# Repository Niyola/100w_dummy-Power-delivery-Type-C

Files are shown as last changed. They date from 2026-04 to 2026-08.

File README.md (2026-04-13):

USB Type-C Power Delivery Tester

A USB-C Power Delivery tester and 100W dummy load, built as part of my Master's thesis at Brno University of Technology.

The board negotiates a USB-PD contract with any USB-C charger, power bank, or laptop, requests different voltages (5V, 9V, 12V, 15V, 20V), and measures what is actually being delivered in real time. It handles up to 100W.

What's inside

The STM32F072CB runs the USB-PD protocol stack. The FUSB302B from onsemi handles the CC line communication. The INA237 from Texas Instruments measures voltage and current on VBUS bidirectionally. It is a 4-layer board, roughly 100mm by 60mm, with dedicated inner planes for ground and 3.3V.

References I used

Twonkie v2.0 by dojoe — https://github.com/dojoe/Twonkie/tree/master
An open source USB-PD sniffer. I followed its approach for the FUSB302B wiring and the CC line level shifting.

TI TPS25751EVM — https://www.ti.com/tool/TPS25751EVM
Texas Instruments' official USB-PD evaluation board. I used it as a reference for the high-current VBUS layout and current sensing.

What I changed

I use a single INA237 for bidirectional current sensing instead of two separate chips. I added a screw terminal output so the board works as a dummy load tester, not just a sniffer. I redesigned the stackup as 4 layers with full ground and 3.3V planes for better power integrity at 100W. I also added test points for bring-up.

About me

Eniola Adesuyi, M.Sc. Communications and Networking, Brno University of Technology. Supervised by Ing. Ondřej Krajsa, Ph.D.

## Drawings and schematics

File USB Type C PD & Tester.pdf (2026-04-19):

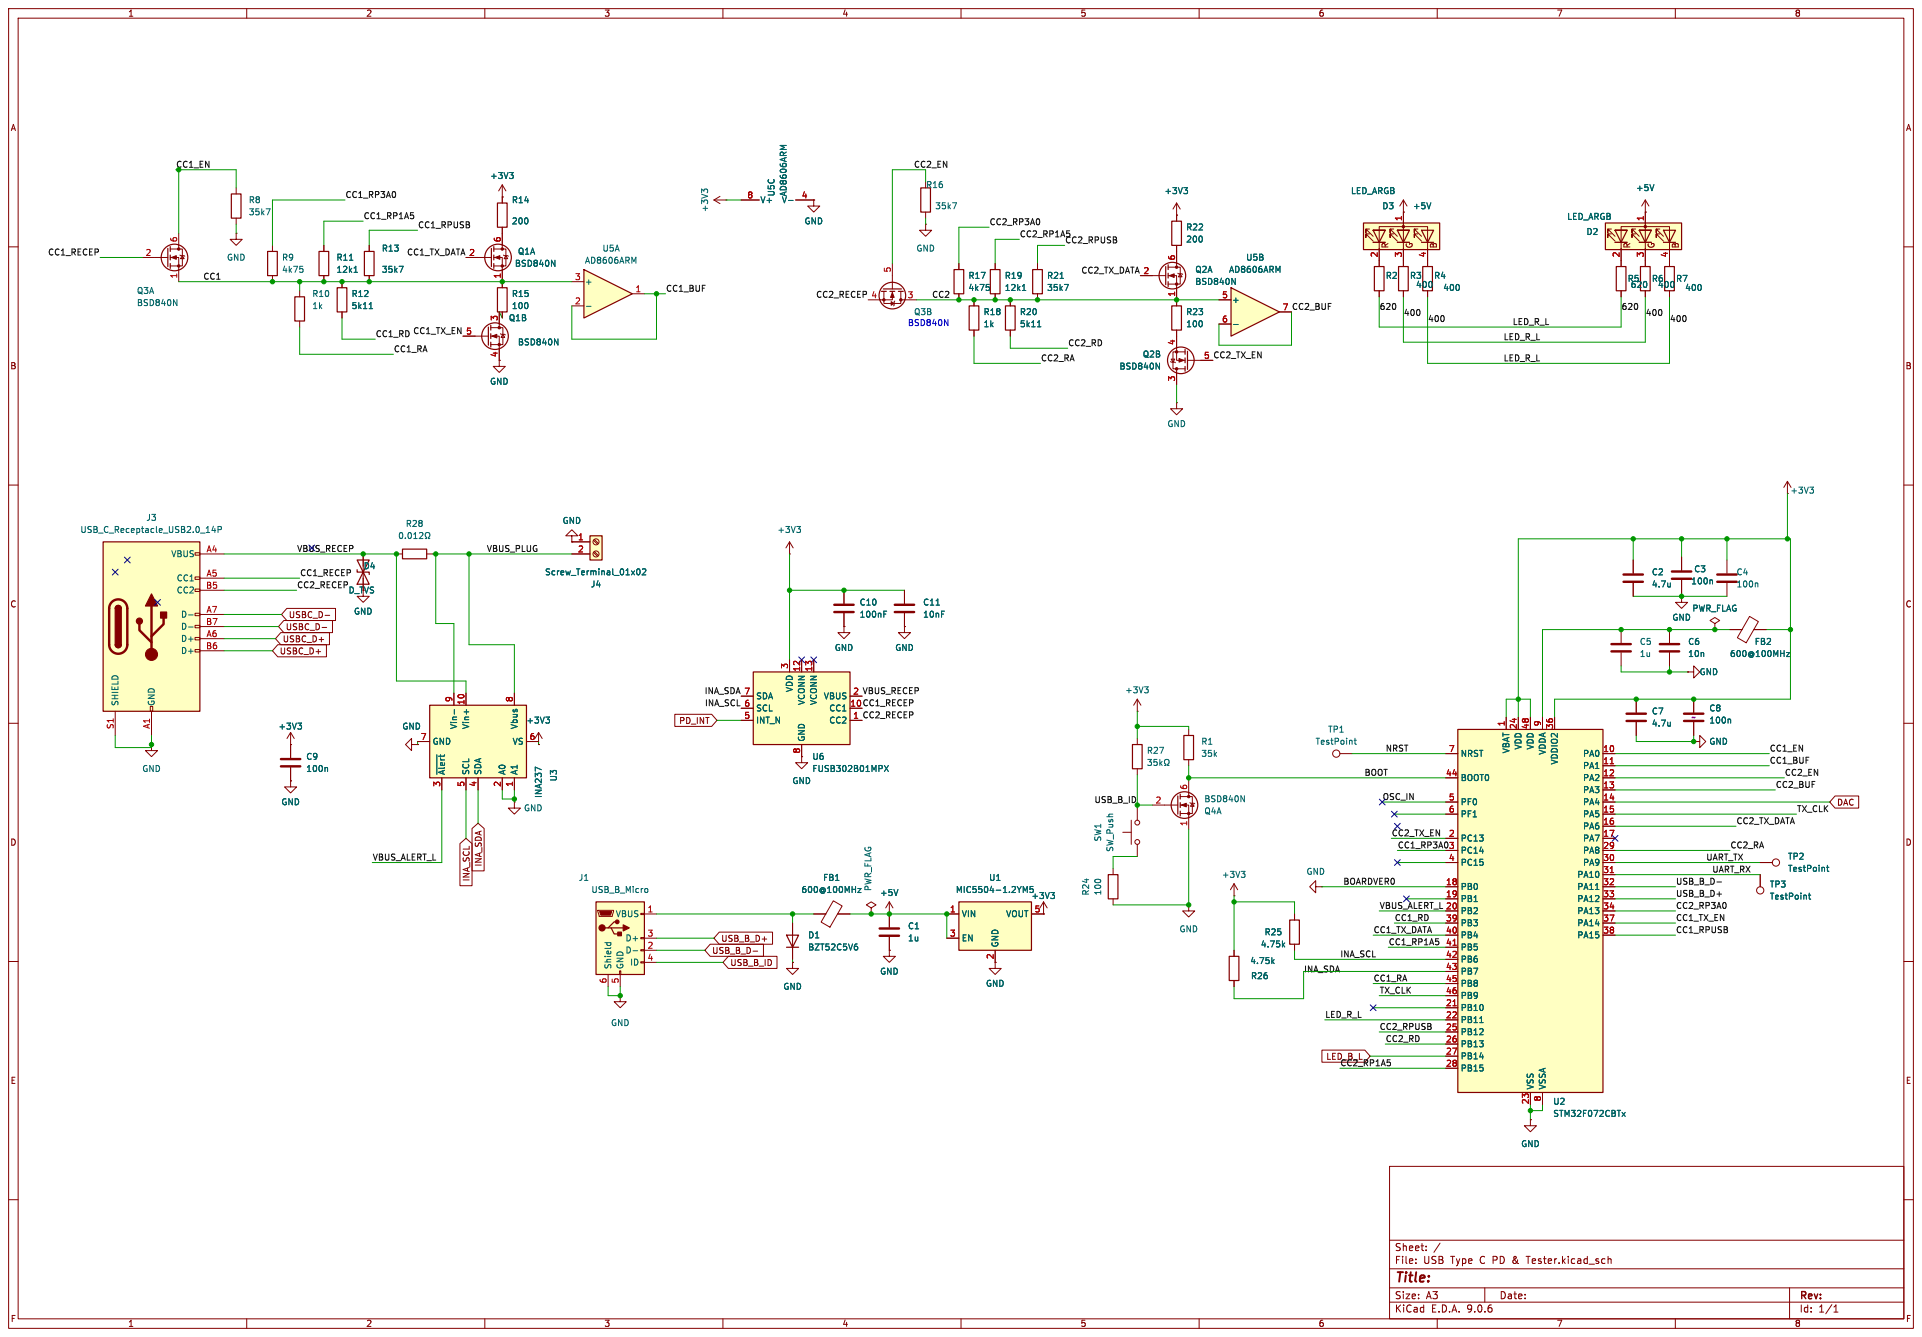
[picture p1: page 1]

3 4 U3 INA237 Vbus 8 Vin+ 10 Vin- 9 VS 6 GND 7 A1

1 VDD 24 VDD 48 VSS 23 VDDA

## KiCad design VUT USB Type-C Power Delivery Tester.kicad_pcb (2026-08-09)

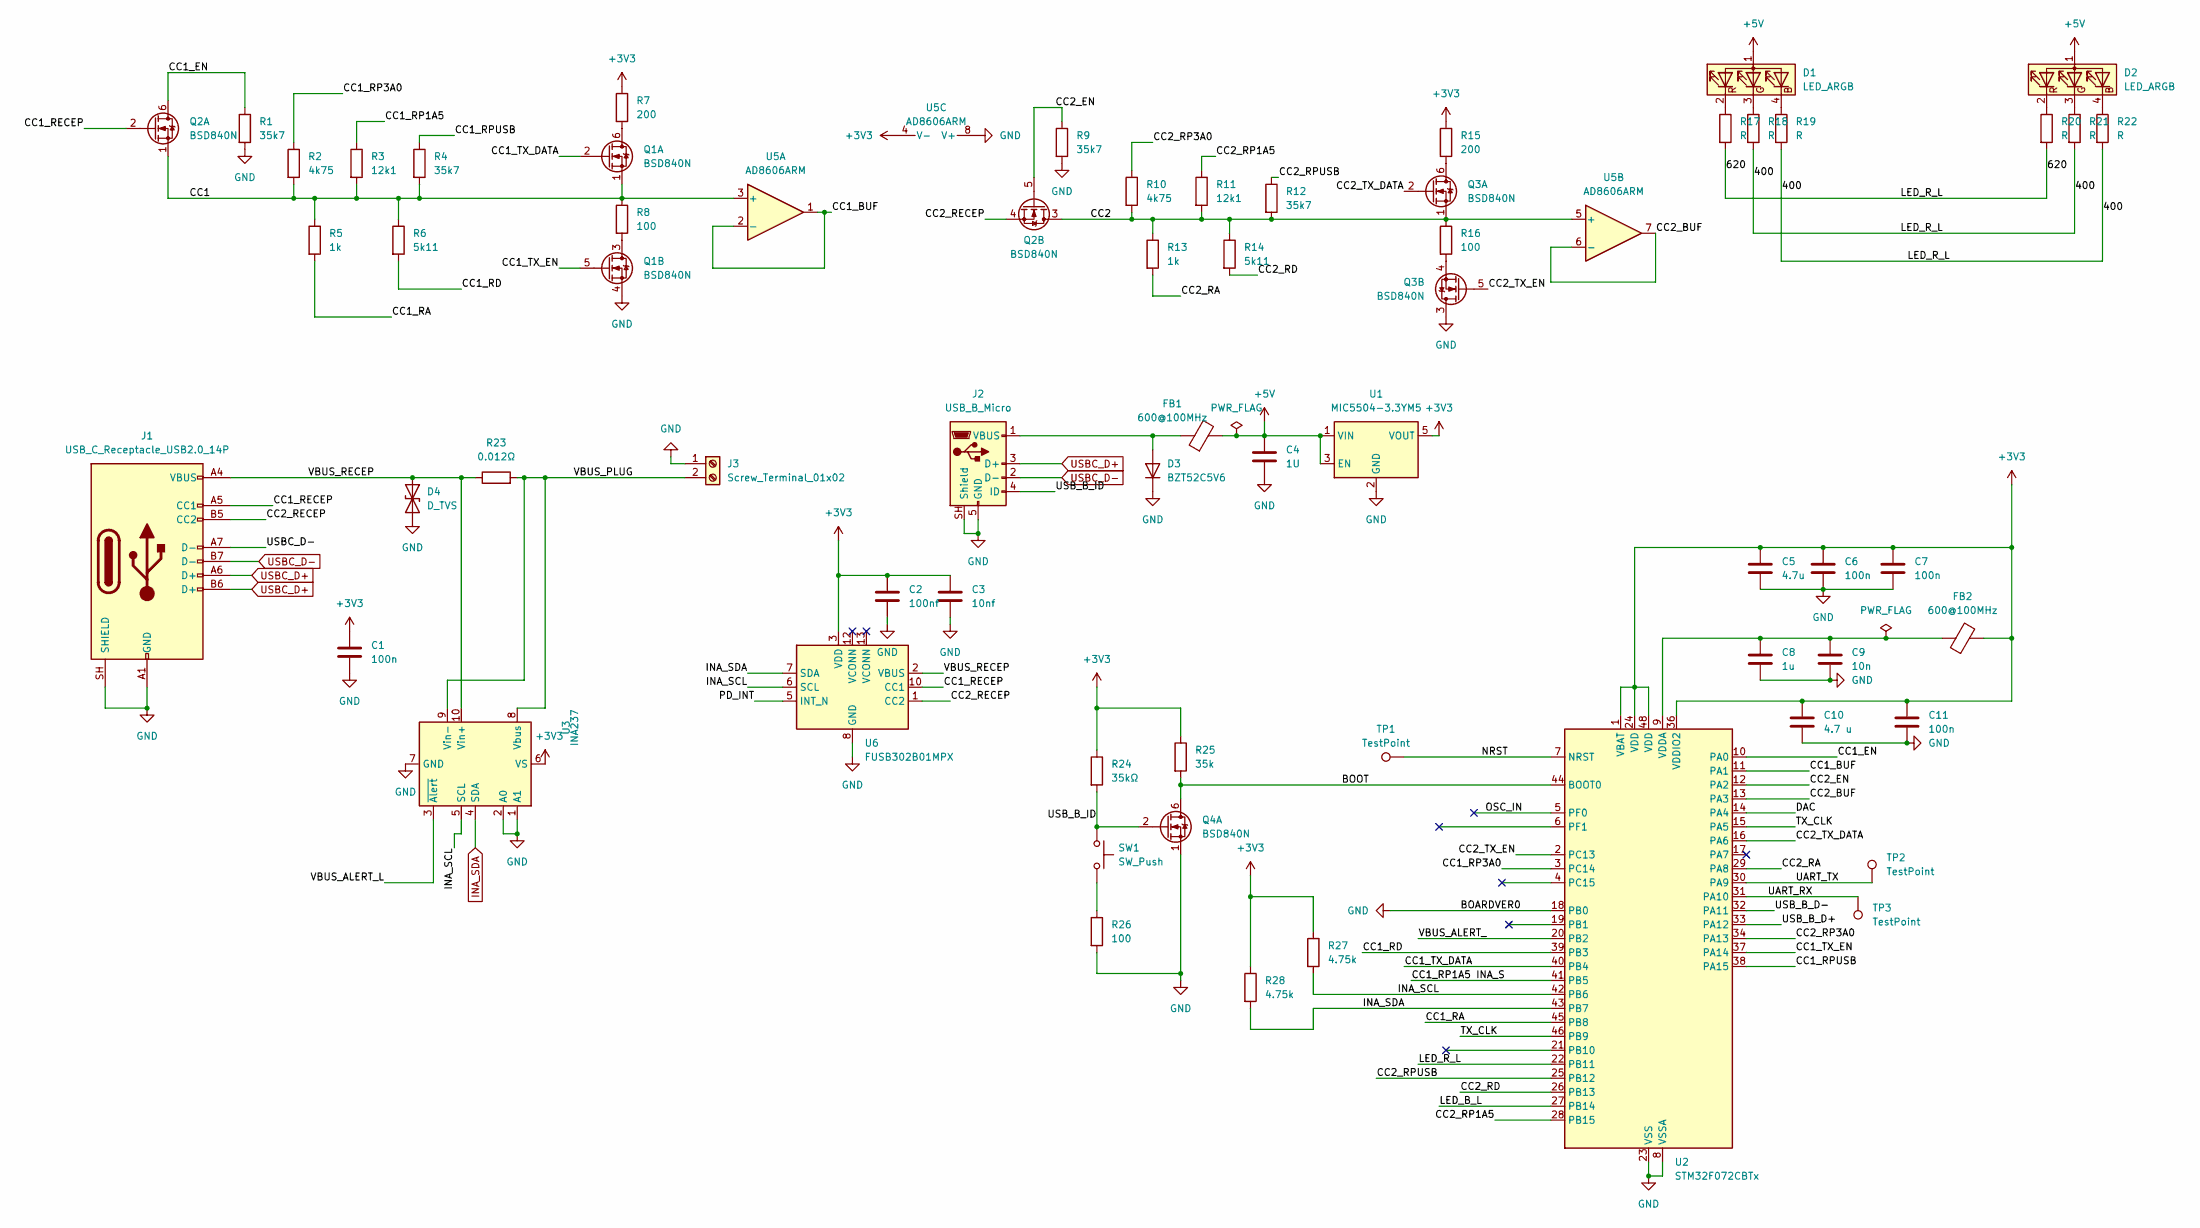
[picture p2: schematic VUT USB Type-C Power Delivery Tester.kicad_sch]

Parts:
C1, C6, C11: 100n; C_0402_1005Metric
C2: 100nf; C_0805_2012Metric
C3: 10nf; C_0402_1005Metric
C4: 1U; C_0402_1005Metric
C5: 4.7u; C_0402_1005Metric
C7: 100n; C_0805_2012Metric
C8: 1u; C_0402_1005Metric
C9: 10n; C_0402_1005Metric
C10: 4.7 u; C_0805_2012Metric
D1, D2: LED_ARGB; LED_Wurth_150044M155260
D3: BZT52C5V6; D_SOD-123
D4: D_TVS; D_SMB
FB1, FB2: 600@100MHz; L_0603_1608Metric
J1: USB_C_Receptacle_USB2.0_14P; USB_C_Receptacle_XKB_U262-16XN-4BVC11
J2: USB_B_Micro; USB_Micro-B_Molex-105017-0001
J3: Screw_Terminal_01x02; TerminalBlock_Phoenix_PT-1,5-2-3.5-H_1x02_P3.50mm_Horizontal
Q1, Q2, Q3, Q4: BSD840N; SOT-363_SC-70-6
R1, R4, R9, R12: 35k7; R_0402_1005Metric
R2, R10: 4k75; R_0402_1005Metric
R3, R11: 12k1; R_0402_1005Metric
R5, R13: 1k; R_0402_1005Metric
R6, R14: 5k11; R_0402_1005Metric
R7, R15: 200; R_0402_1005Metric
R8, R16, R26: 100; R_0402_1005Metric
R17, R18, R19, R20, R21, R22: R; R_0402_1005Metric
R23: 0.012Ω; R_0402_1005Metric
R24: 35kΩ; R_0402_1005Metric
R25: 35k; R_0402_1005Metric
R27, R28: 4.75k; R_0402_1005Metric
SW1: SW_Push; SW_SPST_PTS645Sx43SMTR92
TP1, TP2, TP3: TestPoint; TestPoint_Pad_1.0x1.0mm
U1: MIC5504-3.3YM5; SOT-23-5
U2: STM32F072CBTx; LQFP-48_7x7mm_P0.5mm
U3: INA237; TSSOP-10_3x3mm_P0.5mm
U5: AD8606ARM; MSOP-8_3x3mm_P0.65mm
U6: FUSB302B01MPX; WQFN-14-1EP_2.5x2.5mm_P0.5mm_EP1.45x1.45mm

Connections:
+3V3: C1.1, C2.1, C3.1, C5.1, C6.1, C7.1, C10.1, C11.1, FB2.2, R7.1, R15.1, R24.1, R25.1, R27.1, R28.1, U1.5 (VOUT), U2.1 (VBAT), U2.24 (VDD), U2.36 (VDDIO2), U2.48 (VDD), U3.6 (VS), U5.4 (V-), U6.3 (VDD), U6.4 (VDD)
+5V: C4.1, D1.1 (A), D2.1 (A), FB1.2, U1.1 (VIN), U1.3 (EN)
/400: R17.2, R18.2, R19.2, R20.2, R21.2, R22.2, U2.22 (PB11)
/BOOT: Q4.6 (D), R25.2, U2.44 (BOOT0)
/CC1: Q1.1 (S), Q2.1 (S), R2.2, R3.2, R4.2, R5.1, R6.1, R8.1, U5.3 (+)
/CC1_BUF: U2.11 (PA1), U5.1, U5.2 (-)
/CC1_EN: Q2.6 (D), R1.1, U2.10 (PA0)
/CC1_RA: R5.2, U2.45 (PB8)
/CC1_RD: R6.2, U2.39 (PB3)
/CC1_RECEP: J1.A5 (CC1), Q2.2 (G), U6.10 (CC1), U6.11 (CC1)
/CC1_RP1A5: R3.1
/CC1_RP1A5 INA_S: U2.41 (PB5)
/CC1_RP3A0: R2.1, U2.3 (PC14)
/CC1_RPUSB: R4.1, U2.38 (PA15)
/CC1_TX_DATA: Q1.2 (G), U2.40 (PB4)
/CC1_TX_EN: Q1.5 (G), U2.37 (PA14)
/CC2: Q2.3 (D), Q3.1 (S), R10.2, R11.2, R12.2, R13.1, R14.1, R16.1, U5.5 (+)
/CC2_BUF: U2.13 (PA3), U5.6 (-), U5.7
/CC2_EN: Q2.5 (G), R9.1, U2.12 (PA2)
/CC2_RA: R13.2, U2.29 (PA8)
/CC2_RD: R14.2, U2.26 (PB13)
/CC2_RECEP: J1.B5 (CC2), Q2.4 (S), U6.1 (CC2), U6.14 (CC2)
/CC2_RP1A5: R11.1, U2.28 (PB15)
/CC2_RP3A0: R10.1, U2.34 (PA13)
/CC2_RPUSB: R12.1, U2.25 (PB12)
/CC2_TX_DATA: Q3.2 (G), U2.16 (PA6)
/CC2_TX_EN: Q3.5 (G), U2.2 (PC13)
/DAC: U2.14 (PA4)
/INA_SCL: R27.2, U2.42 (PB6), U3.5 (SCL), U6.6 (SCL)
/LED_B_L: U2.27 (PB14)
/NRST: TP1.1 (1_1), U2.7 (NRST)
/OSC_IN: U2.5 (PF0)
/PD_INT: U6.5 (INT_N)
/TX_CLK: U2.15 (PA5), U2.46 (PB9)
/UART_RX: TP3.1 (1_1), U2.31 (PA10)
/UART_TX: TP2.1 (1_1), U2.30 (PA9)
/USB_B_D+: U2.33 (PA12)
/USB_B_D-: U2.32 (PA11)
/USB_B_ID: J2.4 (ID), Q4.2 (G), R24.2, SW1.1
/VBUS_ALERT_: U2.20 (PB2)
/VBUS_ALERT_L: U3.3 (~Alert)
/VBUS_PLUG: J3.2, R23.2, U3.8 (Vbus), U3.9 (Vin-)
/VBUS_RECEP: D4.1 (A1), J1.A4 (VBUS), J1.A9 (VBUS), J1.B4 (VBUS), J1.B9 (VBUS), R23.1, U3.10 (Vin+), U6.2 (VBUS)
GND: C1.2, C2.2, C3.2, C4.2, C5.2, C6.2, C7.2, C8.2, C9.2, C10.2, C11.2, D3.1 (K), D4.2 (A2), J1.A1 (GND), J1.A12 (GND), J1.B1 (GND), J1.B12 (GND), J1.SH (SHIELD), J2.5 (GND), J2.SH (Shield), J3.1, Q1.4 (S), Q3.3 (D), Q4.1 (S), R1.2, R9.2, R26.2, U1.2 (GND), U2.8 (VSSA), U2.18 (PB0), U2.23 (VSS), U2.35 (VSS), U2.47 (VSS), U3.1 (A1), U3.2 (A0), U3.7 (GND), U5.8 (V+), U6.8 (GND), U6.9 (GND), U6.15 (GND)
INA_SDA: R28.2, U2.43 (PB7), U3.4 (SDA), U6.7 (SDA)
unnamed: D1.4 (BK), R19.1
unnamed: D1.3 (GK), R18.1
unnamed: D1.2 (RK), R17.1
unnamed: D2.4 (BK), R22.1
unnamed: D2.3 (GK), R21.1
unnamed: D2.2 (RK), R20.1
unnamed: D3.2 (A), FB1.1, J2.1 (VBUS)
unnamed: Q1.6 (D), R7.2
unnamed: Q1.3 (D), R8.2
unnamed: Q3.6 (D), R15.2
unnamed: Q3.4 (S), R16.2
unnamed: R26.1, SW1.2
unnamed: C8.1, C9.1, FB2.1, U2.9 (VDDA)
USBC_D+: J1.A6 (D+), J1.B6 (D+), J2.3 (D+)
USBC_D-: J1.A7 (D-), J1.B7 (D-), J2.2 (D-)

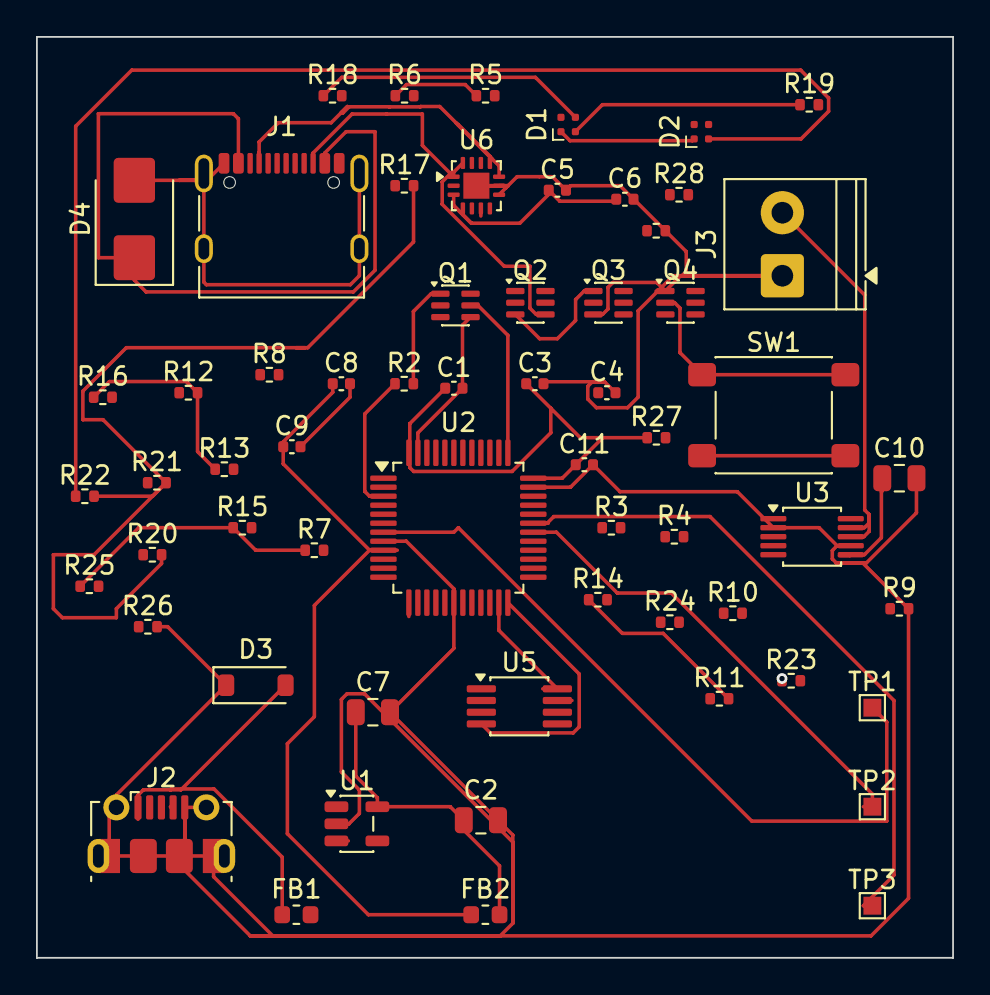
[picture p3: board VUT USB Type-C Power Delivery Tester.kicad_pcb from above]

Board: 4 copper layers, 50.9 x 51.2 mm, 61 parts (0 on the bottom side), 50 nets.

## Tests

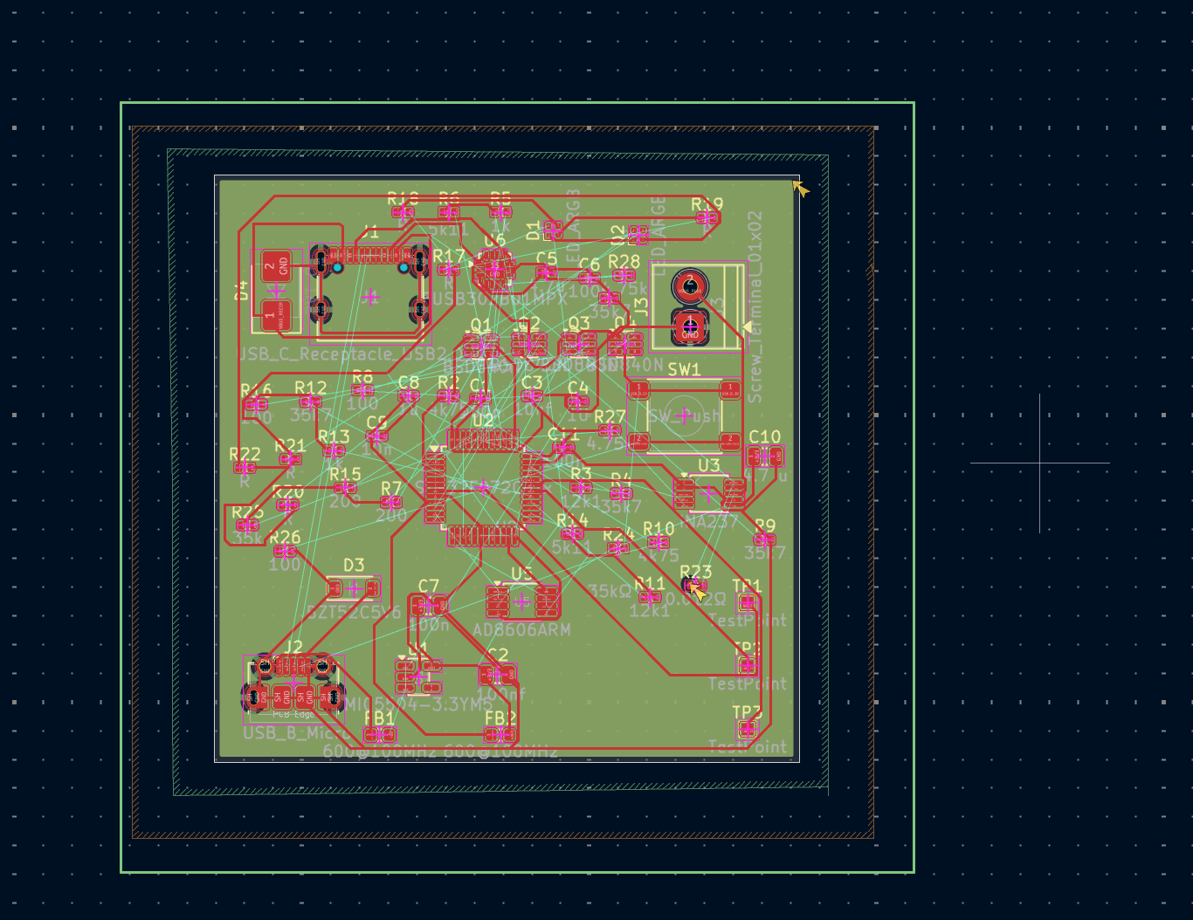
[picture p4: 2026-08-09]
Power delivery Tester PCB .png
